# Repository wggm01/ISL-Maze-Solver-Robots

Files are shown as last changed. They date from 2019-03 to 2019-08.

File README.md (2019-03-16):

# Maze-Solver-Robots
We are working on a proposal to teach secondary teachers how to develop robots that are capable of solving a maze using open source platforms like Arduino and Raspberry.

Project Members:

Javier Romero.
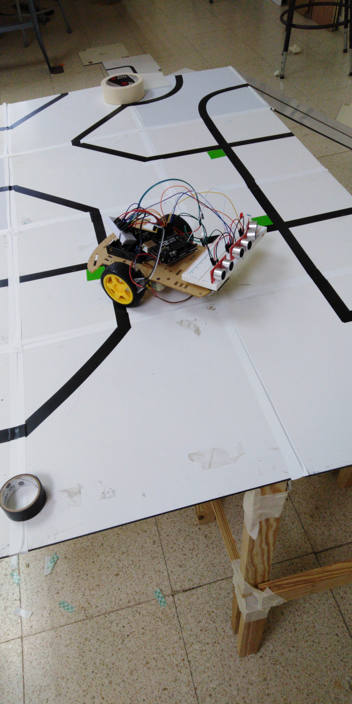
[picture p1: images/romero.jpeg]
Romero
> 

Fatima Batista.
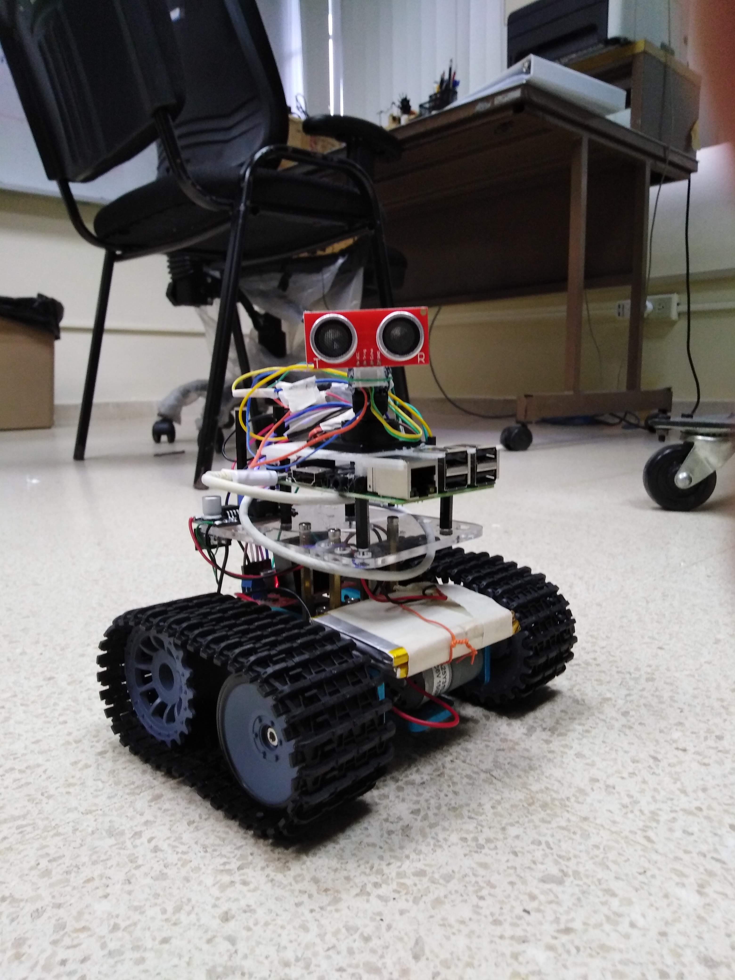
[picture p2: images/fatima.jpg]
Fatima
> 

Sobenis.
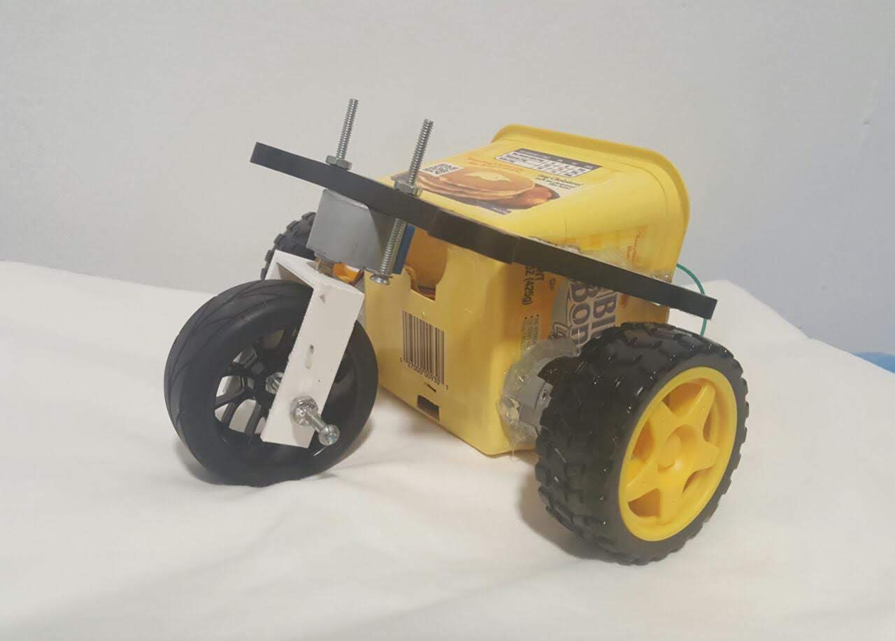
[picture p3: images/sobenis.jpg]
Sobenis
> 

Gabriel Marzullo.
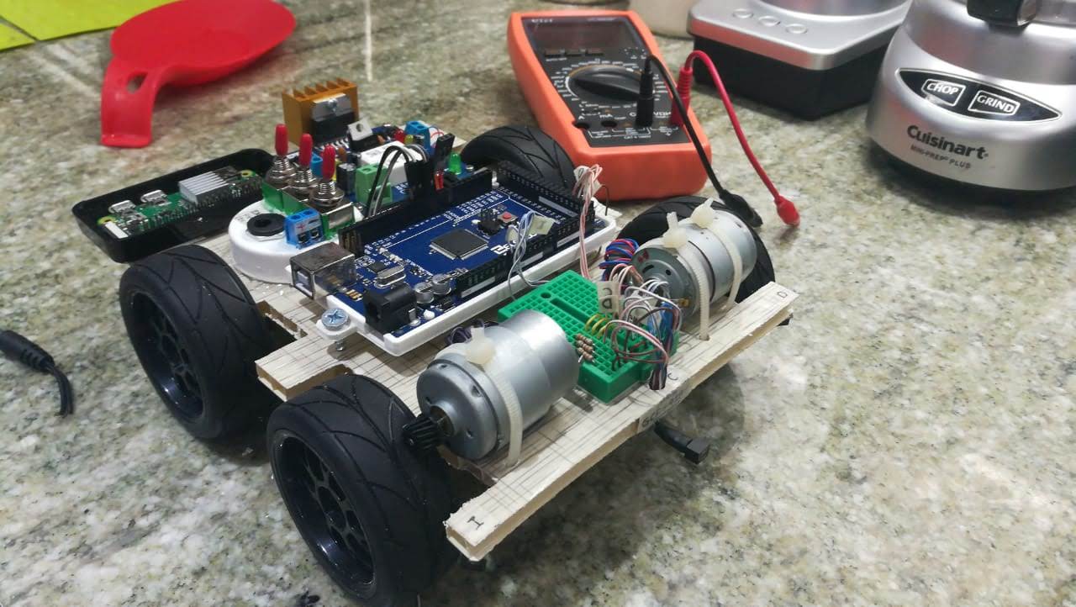
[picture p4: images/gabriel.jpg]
> 

Logistical info: 

Team Name: Intelligent-Systems-Laboratory

Organization: Technological University of Panama

Country: Panama 

Contact person: Danilo Caceres 

Email: danilo.caceres@utp.ac.pa

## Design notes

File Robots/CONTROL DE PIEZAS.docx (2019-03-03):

Articulo | Cantidad | Link | Imagen | Persona | Cantidad

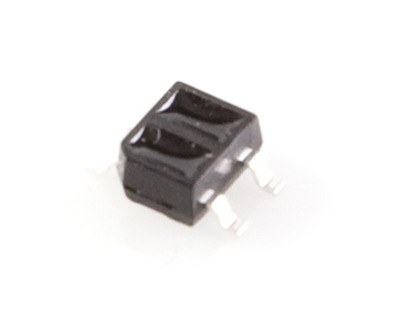
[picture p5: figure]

IR Reflectance Sensor - QRE1113 | 6 | https://www.sparkfun.com/products/9542 | | | 0[actualmente no se donde quedaron]
Optical Detector / Phototransistor - QRD1114 | 6 | https://www.sparkfun.com/products/246 | | Gabriel Marzullo | 3
Mini Photocell | 12 | https://www.sparkfun.com/products/9088 | | Gabriel Marzullo | 2

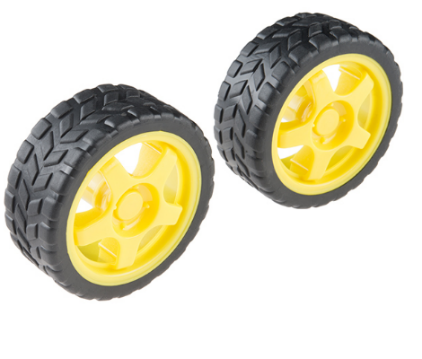
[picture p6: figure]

Wheel - 65mm (Rubber Tire, Pair) | 12 | https://www.sparkfun.com/products/13259 | | Sobenis Javier Romero | 0 2

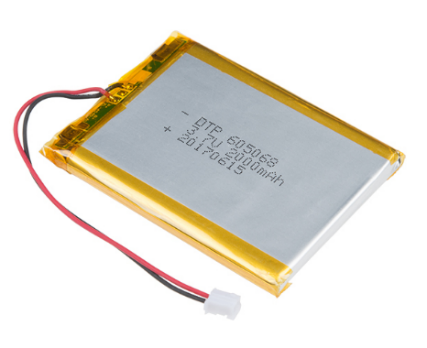
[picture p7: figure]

Baterias | 17 | https://www.sparkfun.com/products/13855 | | Gabriel Marzullo Sobenis Wvaldo Graell UDELAS | 3 0 3 3

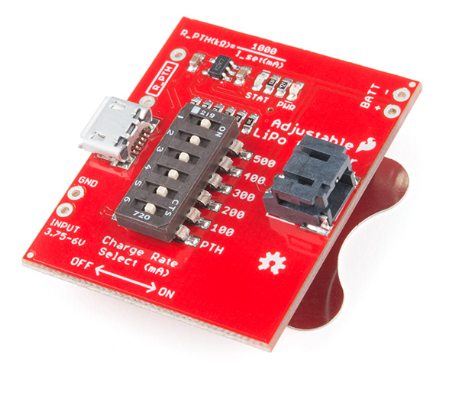
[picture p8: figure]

Cargadores | 6 | https://www.sparkfun.com/products/14380 | | Wvaldo Graell Sobenis Gabriel UDELAS | 1 0 1 1
Regulador de voltaje a 5v | 6 | https://www.sparkfun.com/products/107 | | Gabriel Marzullo | 1

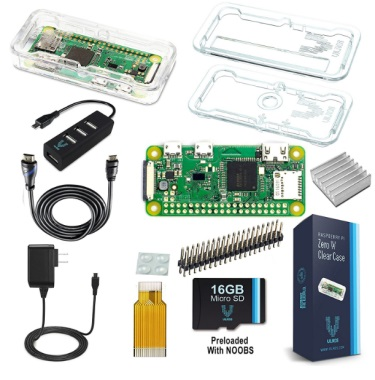
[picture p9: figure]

Raspberry pi Zero | 3 | https://www.amazon.com/gp/product/B0748M1Z1B/ref=ox_sc_sfl_title_1?ie=UTF8&psc=1&smid=AHALS71WJO58T | | Gabriel UDELAS Javier Romero | 1 1 1

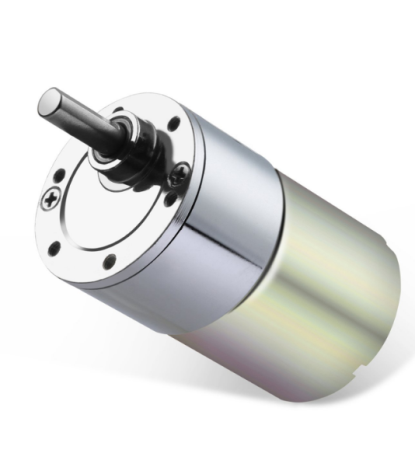
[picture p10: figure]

Motor Dc Con caja reductora | 12 | https://www.amazon.com/gp/product/B072N84V8S/ref=ox_sc_sfl_title_2?ie=UTF8&psc=1&smid=A18IHNL4DD28Y | | Billy Sobenis | 1 0

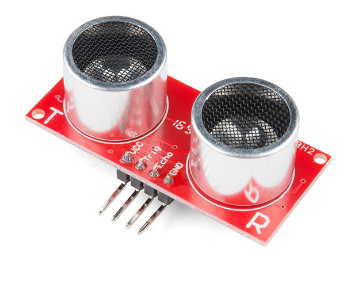
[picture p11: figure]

Sensor Ultrasonico SR-04 | 12 | https://www.sparkfun.com/products/13959 | | Sobenis Javier Romero Wvaldo UDELAS | 0 5 1 2

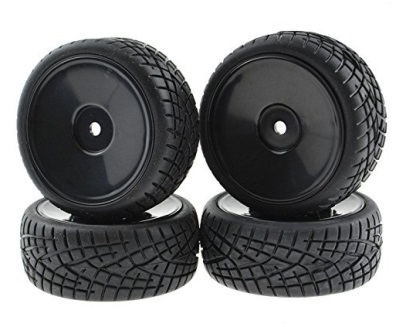
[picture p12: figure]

Llantas con rines | 12 | https://www.amazon.com/gp/product/B01HCVYJ5Q/ref=ox_sc_sfl_title_5?ie=UTF8&psc=1&smid=A9BS2LDT3QKQL | | Gabriel Sobenis Wvaldo | 4[set] 0 4[set]

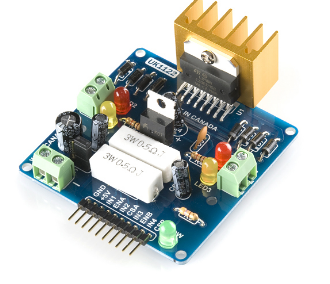
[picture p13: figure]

L298N | 12 | https://www.sparkfun.com/products/9670 | | Gabriel Sobenis Javier | 1 0 1

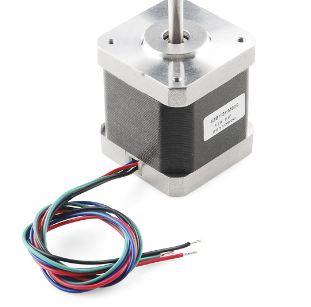
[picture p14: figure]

Stepper Motor - 68 oz.in (400 steps/rev) | 6 | https://www.sparkfun.com/products/10846 | | Wvaldo | 2

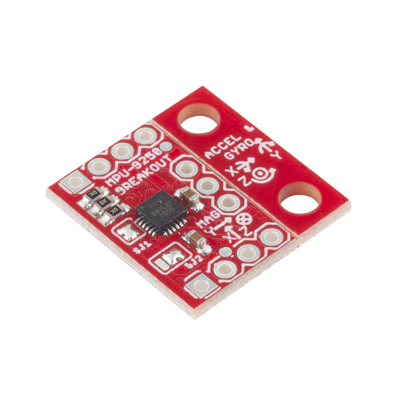
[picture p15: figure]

IMU-Gyroscope (no gimbals) MPU-9250 | 4 | https://www.sparkfun.com/products/13762 | | Gabriel Wvaldo UDELAS | 1 1 1

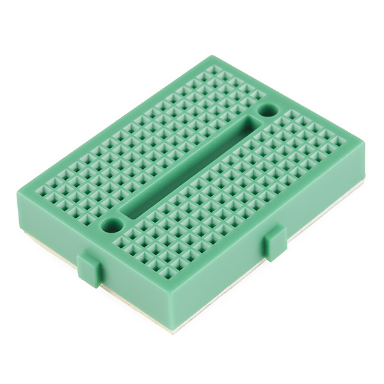
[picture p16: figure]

Mini protoboard modular | 5 | https://www.sparkfun.com/products/12046 | | Sobenis Gabriel Marzullo | 0 1

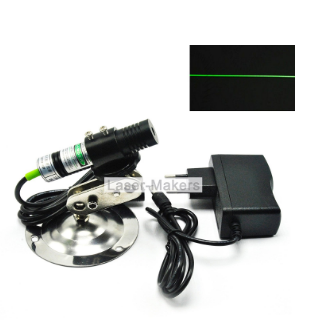
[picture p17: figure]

Laser line | 1 | https://www.amazon.com/gp/product/B00UCMXLXE/ref=ox_sc_sfl_title_8?ie=UTF8&psc=1&smid=A2W34SCE89LQ9K | | Gabriel | Llego 1 actualmente nadie lo usa[29-5-19]
Extensor para camara | 3 | https://www.amazon.com/gp/product/B0748DPHYQ/ref=ox_sc_sfl_title_9?ie=UTF8&psc=1&smid=A1N6DLY3NQK2VM

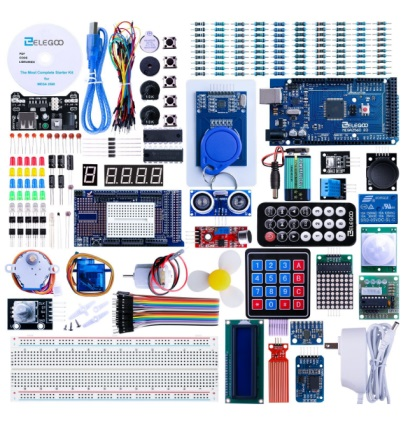
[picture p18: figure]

Arduino MEGA | 3 | https://www.amazon.com/gp/product/B01EWNUUUA/ref=ox_sc_sfl_title_10?ie=UTF8&psc=1&smid=A2WWHQ25ENKVJ1

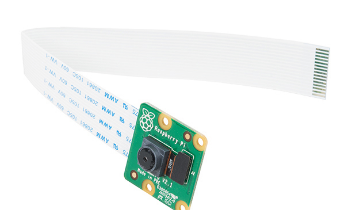
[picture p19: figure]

RPI CAMERA MODULO V2 | 3 | https://www.sparkfun.com/products/14028

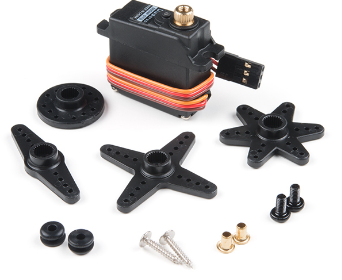
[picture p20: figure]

Servo - Generic Metal Gear (Micro Size) | 6 | https://www.sparkfun.com/products/14760 | | Gabriel Wvaldo Graell | 1 3

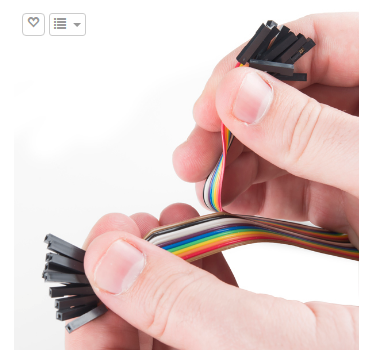
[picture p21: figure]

Jumpers hembra-hembra | 4 | https://www.sparkfun.com/products/12796

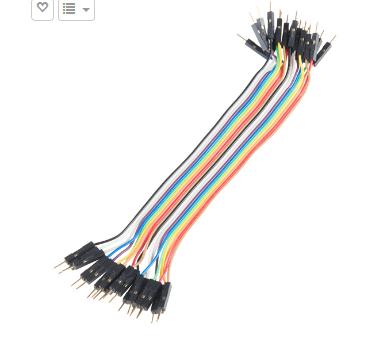
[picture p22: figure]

Jumpers macho-macho | 4 | https://www.sparkfun.com/products/12795

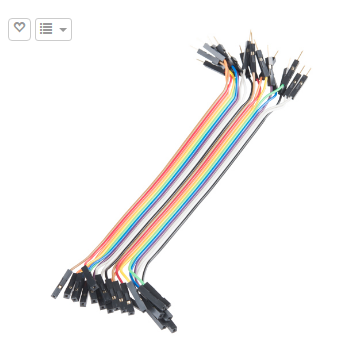
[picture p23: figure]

Jumpers macho-hembra | 4 | https://www.sparkfun.com/products/12794

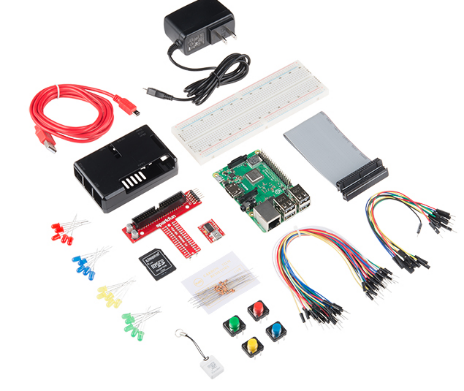
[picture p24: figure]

Raspberry pi 3 model b+ | 3 | https://www.sparkfun.com/products/14644 | | Wvaldo Kelvin | 1 1
Arduino Mega expansionshield | 3 | https://www.sparkfun.com/products/14753 | | Gabriel

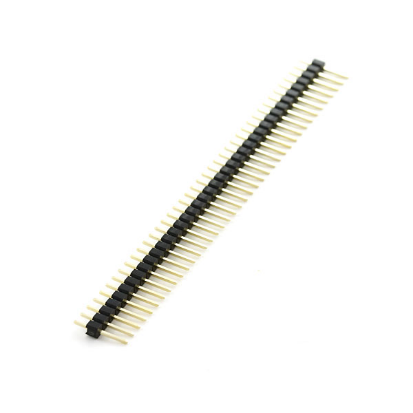
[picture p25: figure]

Header pins macho | 8 | https://www.sparkfun.com/products/116 | | Wvaldo | 1

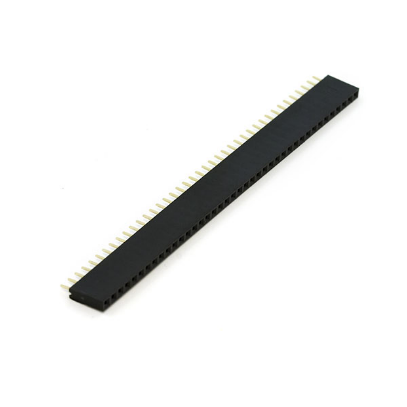
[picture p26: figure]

Header pins hembra | 20 | https://www.sparkfun.com/products/115

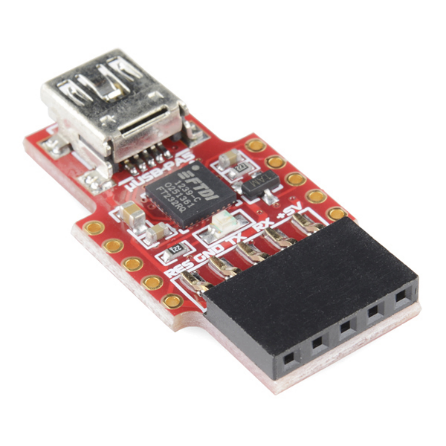
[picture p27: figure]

Puente USB a puerto SERIAL | 1 | https://www.sparkfun.com/products/11814

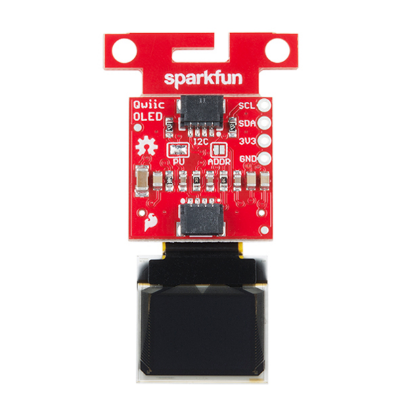
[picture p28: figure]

Pantalla micro OLED | 3 | https://www.sparkfun.com/products/14532 | | Gabriel Wvaldo | 1 1

*Los Artículos con enlaces en negrita no se consiguieron en sparkfun o no estaban disponibles en kits.

ROBOCUP JUNIOR 2018 RESCUE MAZE

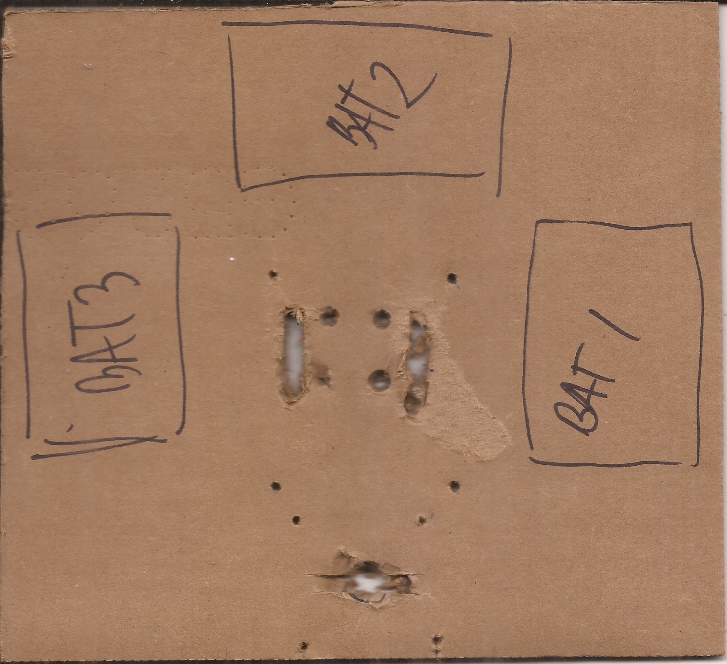
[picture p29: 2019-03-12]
Robots/Fatima/MEJORAS/Nivel2.jpg

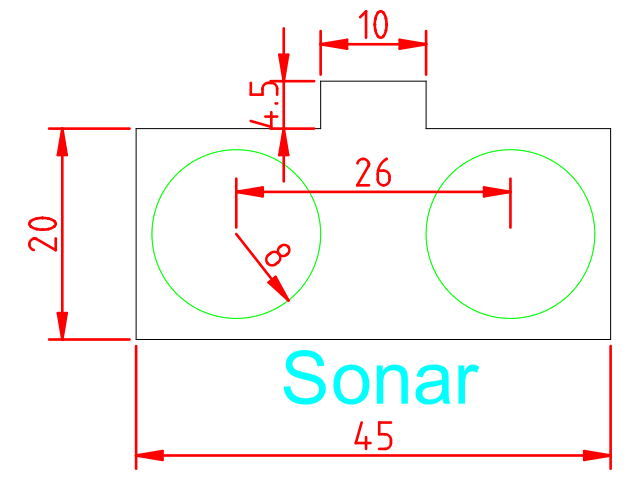
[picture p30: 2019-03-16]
Robots/Fatima/MEJORAS/sonar_anotaciones.png

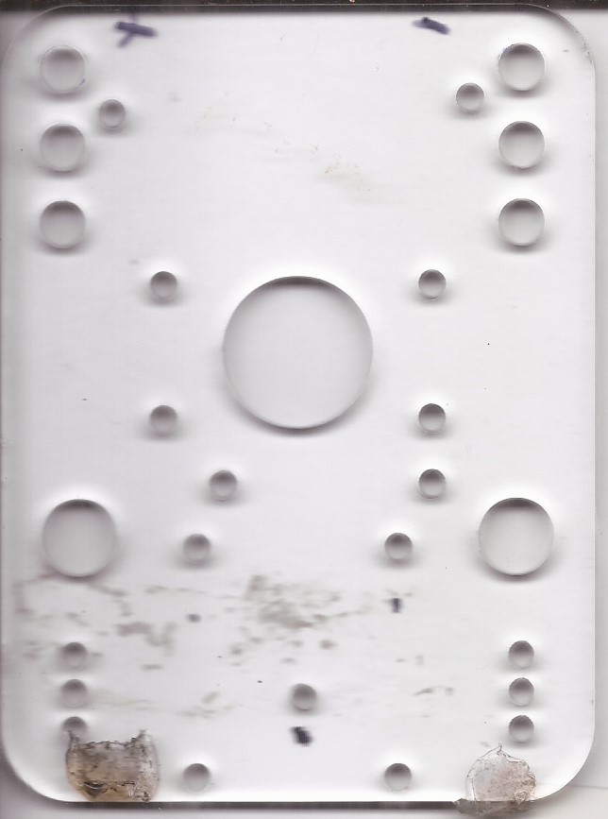
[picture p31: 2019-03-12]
Robots/Fatima/MEJORAS/base de arriba.jpg

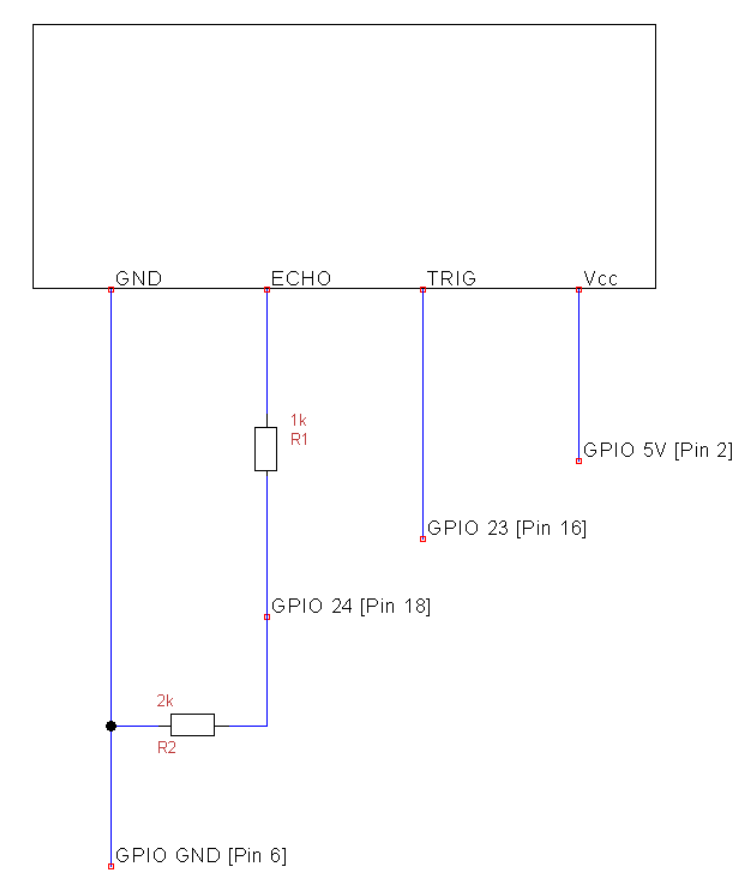
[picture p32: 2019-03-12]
Robots/Fatima/GRAFICOS/divisor.PNG

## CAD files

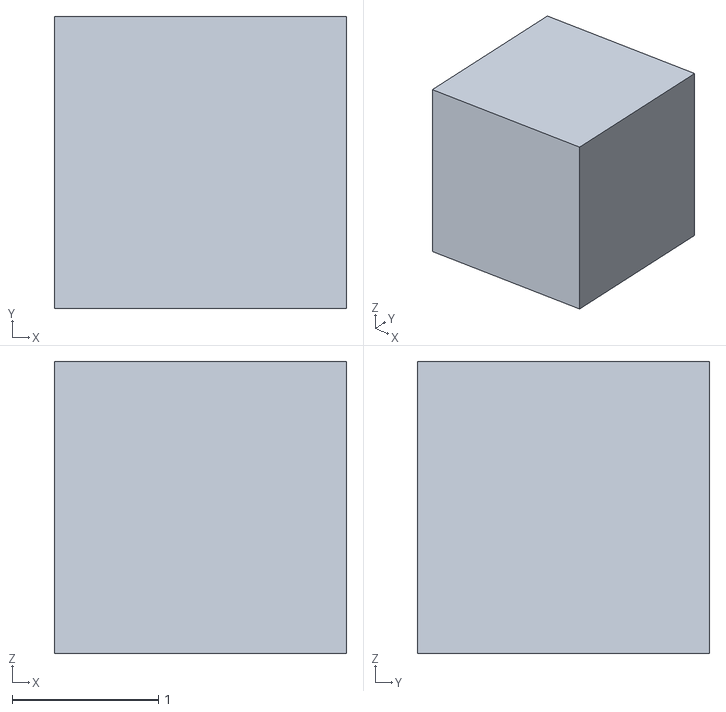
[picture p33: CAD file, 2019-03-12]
Robots/Fatima/IMUvi/data/box/box-C3F_V3F.obj
2.00 x 2.00 x 2.00

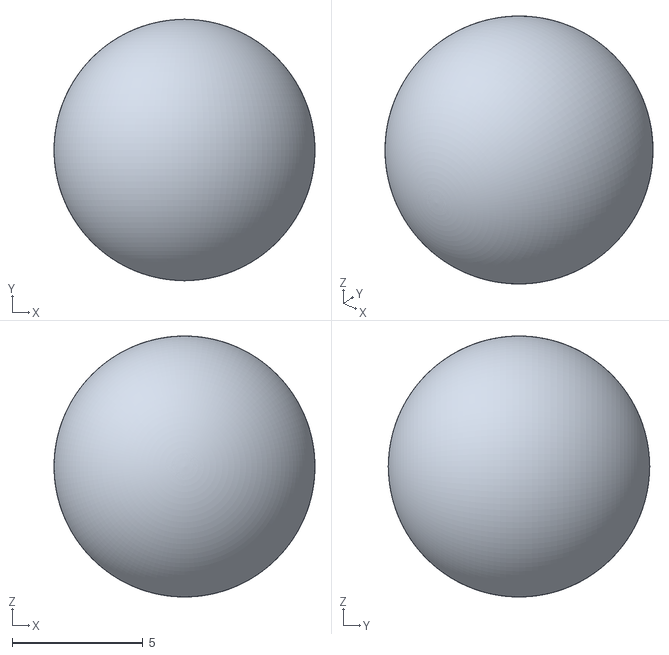
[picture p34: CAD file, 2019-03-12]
Robots/Fatima/IMUvi/data/usados/earth.obj
9.98 x 10.00 x 9.98

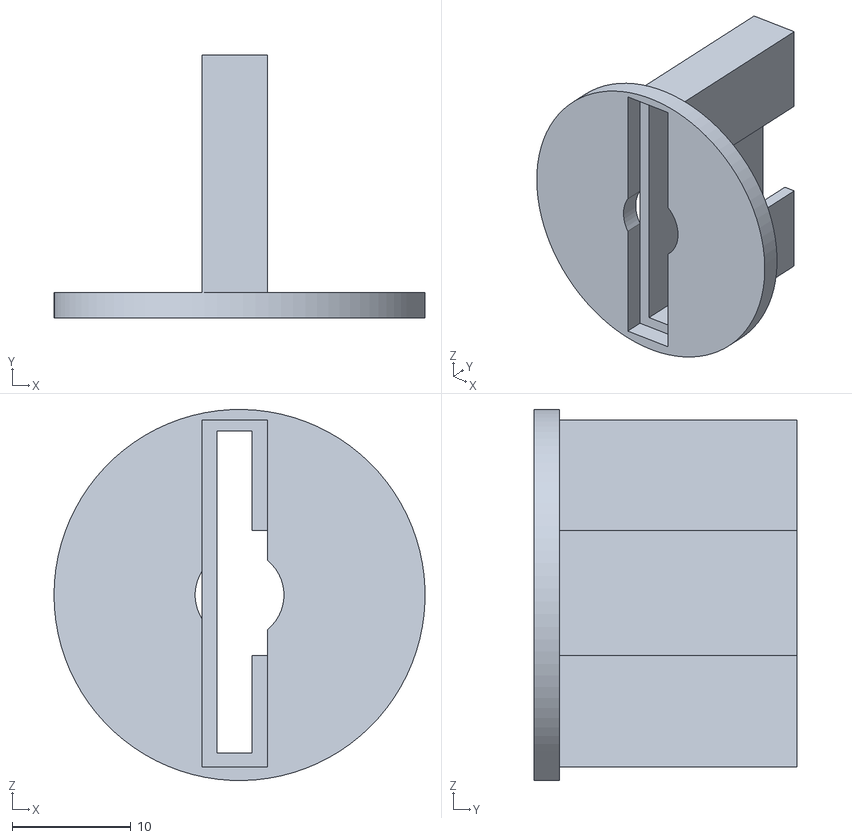
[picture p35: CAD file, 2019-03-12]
Robots/Fatima/IMUvi/Frpi.obj
31.2 x 22.1 x 31.2

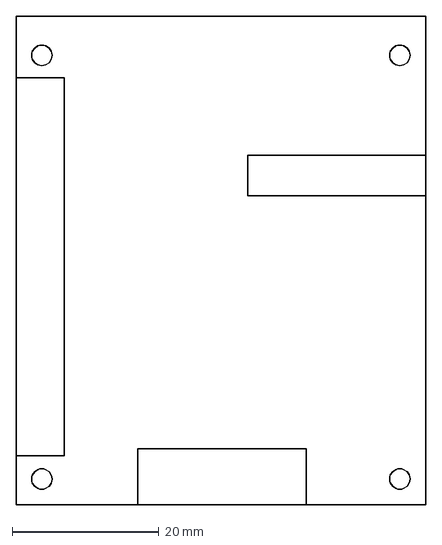
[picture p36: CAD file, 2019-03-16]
Robots/Fatima/MEJORAS/test ajuste rpi.dxf
55.8 x 66.6 mm

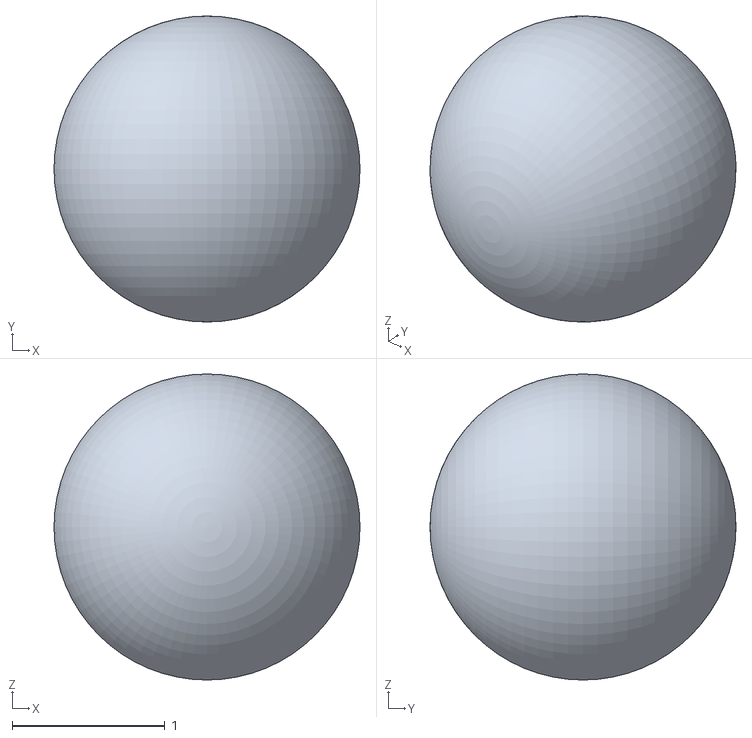
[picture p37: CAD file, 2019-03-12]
Robots/Fatima/not used/data/usados/uv_sphere.obj
2.00 x 2.00 x 2.00

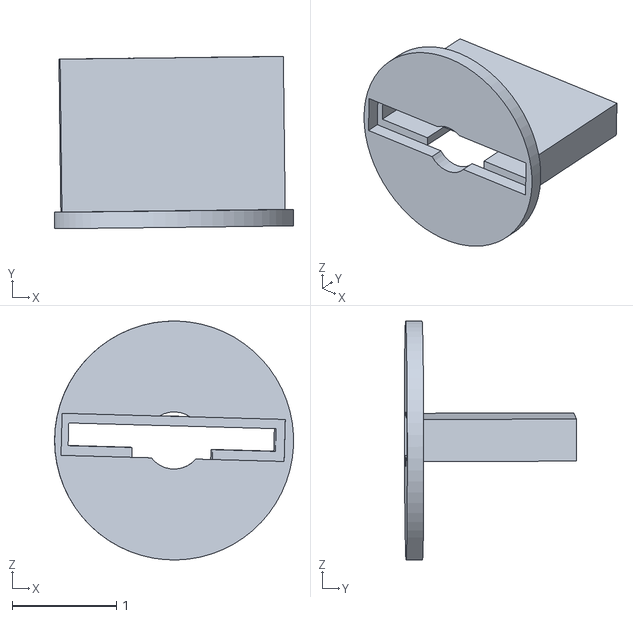
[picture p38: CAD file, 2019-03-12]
Robots/Fatima/IMUvi/data/usados/testobj.obj
2.29 x 1.65 x 2.29

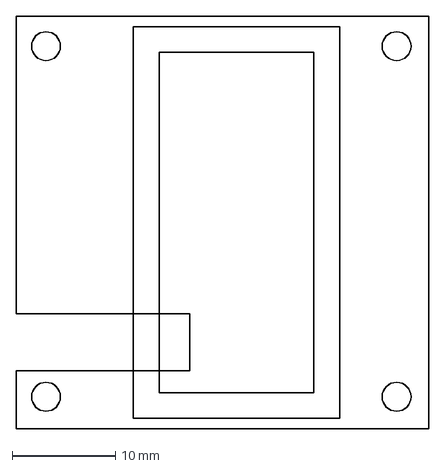
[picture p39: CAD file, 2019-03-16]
Robots/Fatima/MEJORAS/test ajuste servo.dxf
40.0 x 40.0 mm

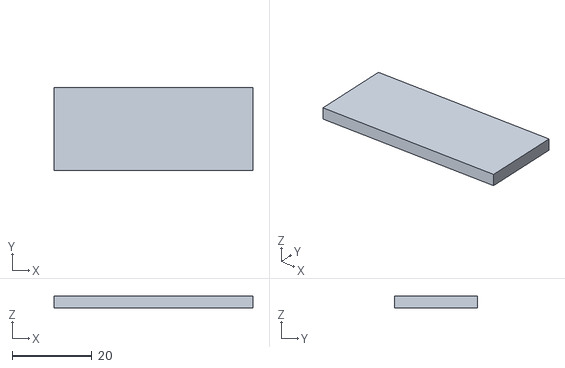
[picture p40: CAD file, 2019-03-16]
Robots/Fatima/MEJORAS/LockHCSR04.stl
50.0 x 20.8 x 3.00

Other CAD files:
Robots/Fatima/IMUvi/data/CUBE.obj
Robots/Fatima/not used/data/box/box-T2F_N3F_V3F.obj
Robots/Fatima/not used/data/CUBE.obj
Robots/Fatima/IMUvi/data/box/box-V3F.obj
Robots/Fatima/not used/data/box/box-T2F_V3F.obj
Robots/Fatima/IMUvi/data/box/box-T2F_N3F_V3F.obj
Robots/Fatima/not used/data/box/box-T2F_C3F_V3F.obj
Robots/Fatima/not used/data/usados/testobj2.obj
Robots/Fatima/IMUvi/data/box/box-N3F_V3F.obj
Robots/Fatima/IMUvi/data/box/box-T2F_C3F_V3F.obj
Robots/Fatima/IMUvi/data/box/box-T2F_V3F.obj
Robots/Fatima/IMUvi/data/usados/testobj2.obj
Robots/Fatima/MEJORAS/Base Radar.stl
Robots/Fatima/MEJORAS/Base para Servo.stl
Robots/Fatima/MEJORAS/CONTROL.dxf
Robots/Fatima/MEJORAS/CoverHCSR04.stl
Robots/Fatima/MEJORAS/SISTEMA DE BATERIAS.dxf
Robots/Fatima/MEJORAS/pcblocations.dxf
Robots/Fatima/MEJORAS/pn1.dxf
Robots/Fatima/MEJORAS/pn2.dxf
Robots/Fatima/MEJORAS/sonar_cotas.dxf
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

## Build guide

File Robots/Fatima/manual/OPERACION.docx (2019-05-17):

OPERACION | LED | MENSAJE EN OLED(I2C)
INICIO DE PROGRAMA | SE MANTIENE ENCENDIDO HASTA QUE EL ARDUINO SE INICIALIZE | INICIO DE PROGRAMA
ELECCION DE MODO | CONMUTA CADA 0.25S HASTA QUE SE ELIJA UN MODO, CUANDO SE ELIJE UN MODO DE SE APAGA | SELECCIONE MODO: B1 MAZE B2 MANUAL

MODO MAZE
ACTIVACION DEBUG | NO REALIZA NINGUNA OPERACION | B1 DEBUG B2 !DEBUG
MODO MAZE ACTIVO | LED PARPADEA CADA 1S TRES VECES | MODO MAZE ACTIVO: TIME: 00:00:00
REINICIO DE PROGRAMA(b1) MODO MAZE ACTIVO | NO HACE NADA | SEE YOU
CIERRE DE PROGRAMA(b2) MODO MAZE ACTIVO | NO HACE NADA | BYE BYE
MODO MANUAL ACTIVO | LED PARPADE 5 VECES CADA 0.5S | MODO MANUAL ACTIVO
BLE SERVER | NO HACE NADA | BLE WAITING
TCP SERVER | NO HACE NADA | TCP WAITING
REINICIO DE PROGRAMA(b1) MODO MANUAL ACTIVO | NO HACE NADA | SEE YOU
CIERRE DE PROGRAMA(b2) MODO MANUAL ACTIVO | NO HACE NADA | BYE BYE

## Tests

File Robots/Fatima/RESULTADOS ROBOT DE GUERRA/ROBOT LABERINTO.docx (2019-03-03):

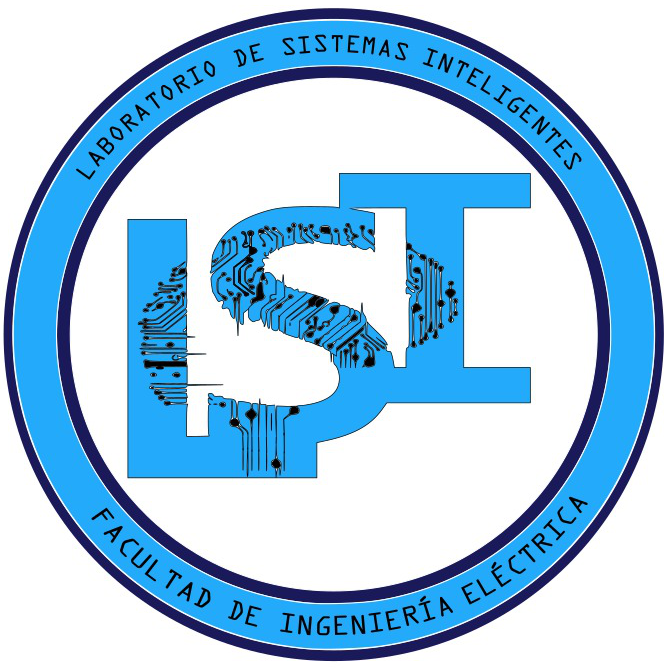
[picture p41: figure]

# ROBOT LABERINTO

UNIDAD AUTONOMA CON NAVEGACION MEDIANTE TECNICAS DE TRATAMIENTO DE SEÑALES DIGITALES

Wvaldo Graell | Josue Rodriguez

Asesores: Danilo Caceres | Fernando Merchan

Laboratorio de Sistemas Inteligentes

Datos Recolectados el 18 de mayo de 2019 hora: 9:30pm

[NOTA: EN TODOS LOS ESCENARIOS CERO GRADOS ESTA A LA DERECHA ]

[ESCENARIO SIN SALIDA]

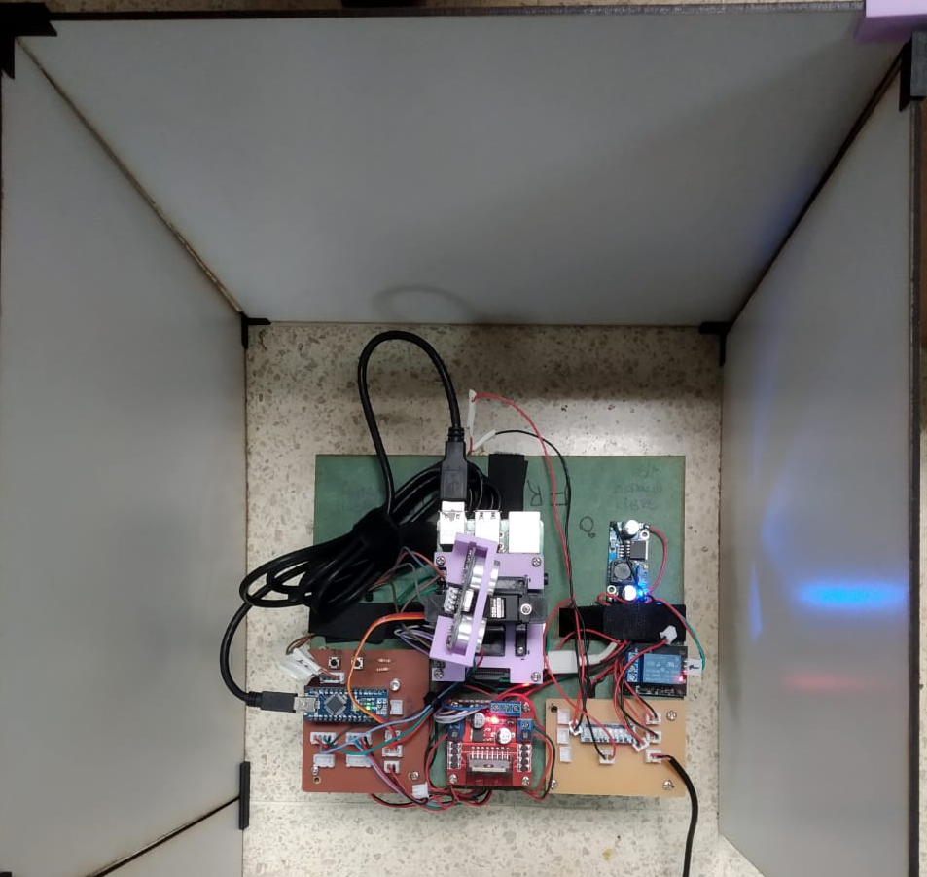
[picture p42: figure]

[GRAFICO EN COORDENADAS RECTANGULARES]

[GRAFICO DE GRADOS VS DISTANCIA]

[ESCENARIO GIRO A LA DERECHA]

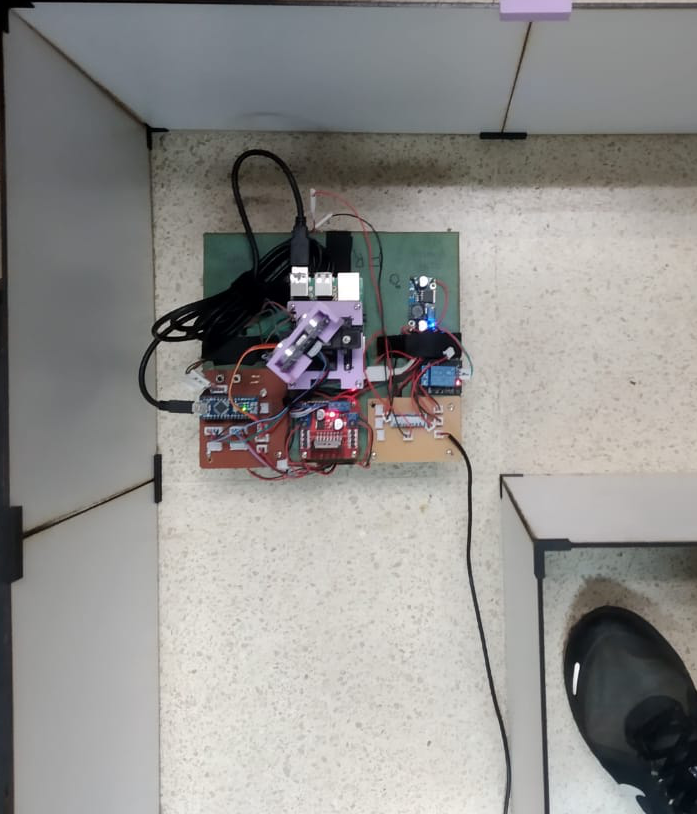
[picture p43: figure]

[GRAFICO EN COORDENADAS RECTANGULARES]

[GRAFICO DE GRADOS VS DISTANCIA]

[ESCENARIO SEGUIR DERECHO]

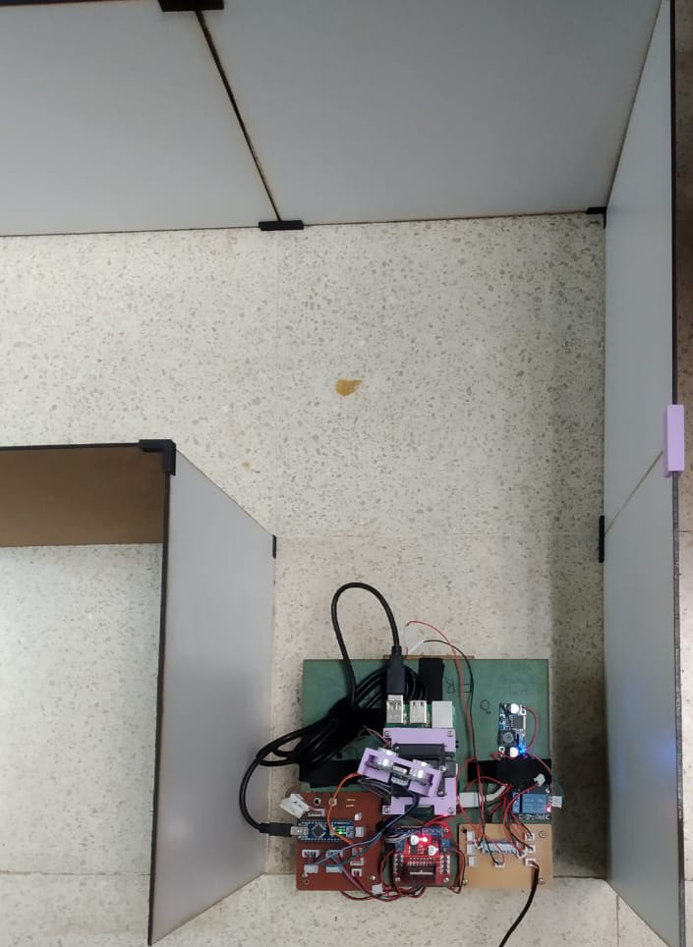
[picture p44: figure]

[GRAFICO EN COORDENADAS RECTANGULARES]

[GRAFICO DE GRADOS VS DISTANCIA]

[ESCENARIO GIRO A LA IZQUIERDA]

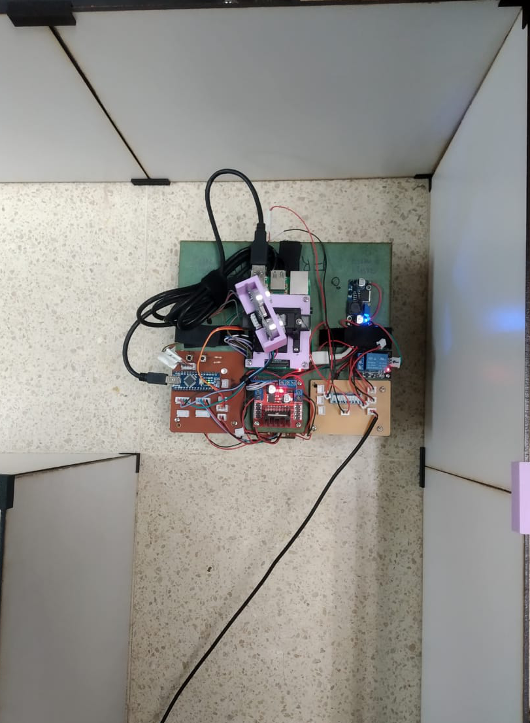
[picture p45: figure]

[GRAFICO EN COORDENADAS RECTANGULARES]

[GRAFICO DE GRADOS VS DISTANCIA]

[EL CODIGO QUE CONTROLA AL SERVO ESTA LIMITADO DE 5 A 170 GRADOS ESTO SE HIZO PORQUE EL REGULADOR DE 5V QUE ALIMENTA AL SERVO PRESENTABA BAJO VOLTAJE CUANDO EL SERVO LLEGABA A LOS EXTREMOS ]

[EL CODIGO QUE CONTROLA AL SENSOR DE DISTANCIA ESTA LIMITADO A 40 CM]

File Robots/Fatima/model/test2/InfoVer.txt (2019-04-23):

GravoStyle GS7 Build 3
7.0.0.0 build B003 at 29/11/2012

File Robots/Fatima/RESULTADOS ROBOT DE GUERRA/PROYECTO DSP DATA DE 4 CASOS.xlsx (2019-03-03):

Grados | Distancia | Radianes | RectX | RectY | GRAFICA EN RECTANGULAR |  |  |  |  |  |  | GRAFICA ANGULO EN GRADOS VS DISTANCIA |  | ESCENARIO
6 | 0 | 0.1047197551 | 0 | 0
7 | 13 | 0.1221730476 | 12.90309997 | 1.584301464
8 | 13 | 0.1396263402 | 12.87348489 | 1.809250312
9 | 13 | 0.1570796327 | 12.83994843 | 2.033648046
10 | 13 | 0.1745329252 | 12.80250079 | 2.25742631
11 | 15 | 0.1919862177 | 14.72440775 | 2.862134931
12 | 13 | 0.2094395102 | 12.71591881 | 2.702851981
13 | 13 | 0.2268928028 | 12.66681084 | 2.924363706
14 | 13 | 0.2443460953 | 12.61384444 | 3.144984643
15 | 14 | 0.2617993878 | 13.52296157 | 3.623466631
16 | 13 | 0.2792526803 | 12.49640205 | 3.583285626
17 | 13 | 0.2967059728 | 12.43196183 | 3.800832161
18 | 13 | 0.3141592654 | 12.36373471 | 4.017220927
19 | 13 | 0.3316125579 | 12.29174148 | 4.232386008
20 | 13 | 0.3490658504 | 12.21600407 | 4.446261863
21 | 13 | 0.3665191429 | 12.13654554 | 4.658783344 |  |  |  |  |  |  |  |  |  | SIN SALIDA
22 | 13 | 0.3839724354 | 12.05339011 | 4.869885714
23 | 13 | 0.401425728 | 11.96656309 | 5.07950467
24 | 13 | 0.4188790205 | 11.87609095 | 5.28757636
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

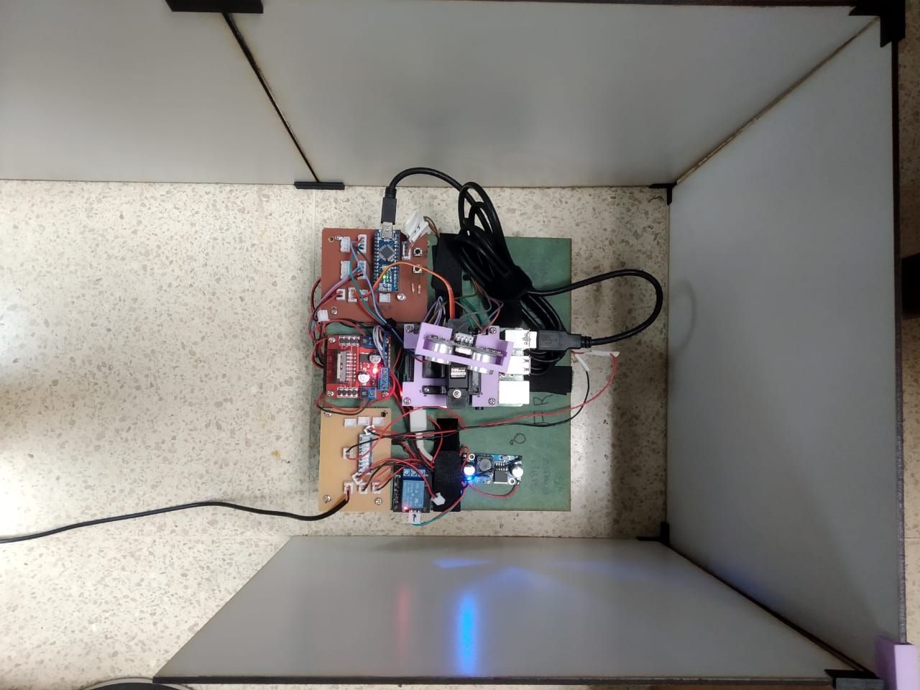
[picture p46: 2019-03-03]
Robots/Fatima/RESULTADOS ROBOT DE GUERRA/Encerrado.jpeg

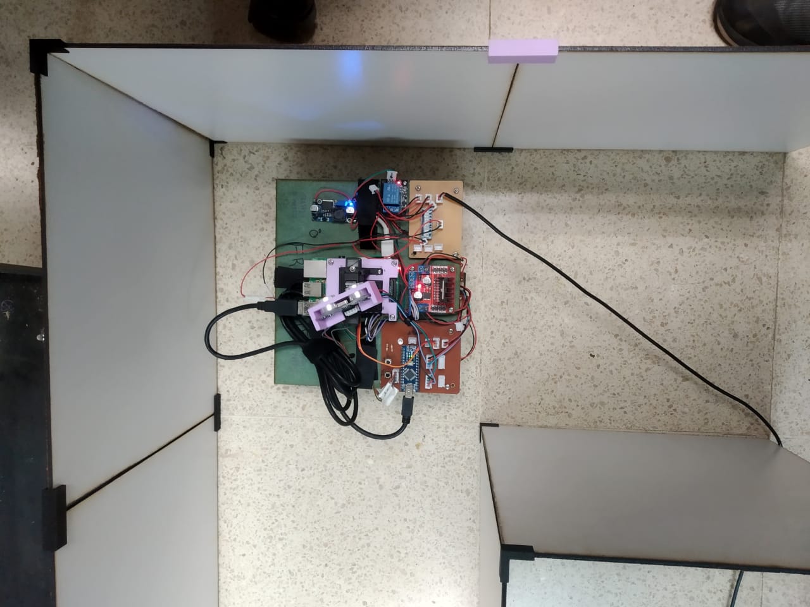
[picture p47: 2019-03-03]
Robots/Fatima/RESULTADOS ROBOT DE GUERRA/Giro a la izquierda.jpeg

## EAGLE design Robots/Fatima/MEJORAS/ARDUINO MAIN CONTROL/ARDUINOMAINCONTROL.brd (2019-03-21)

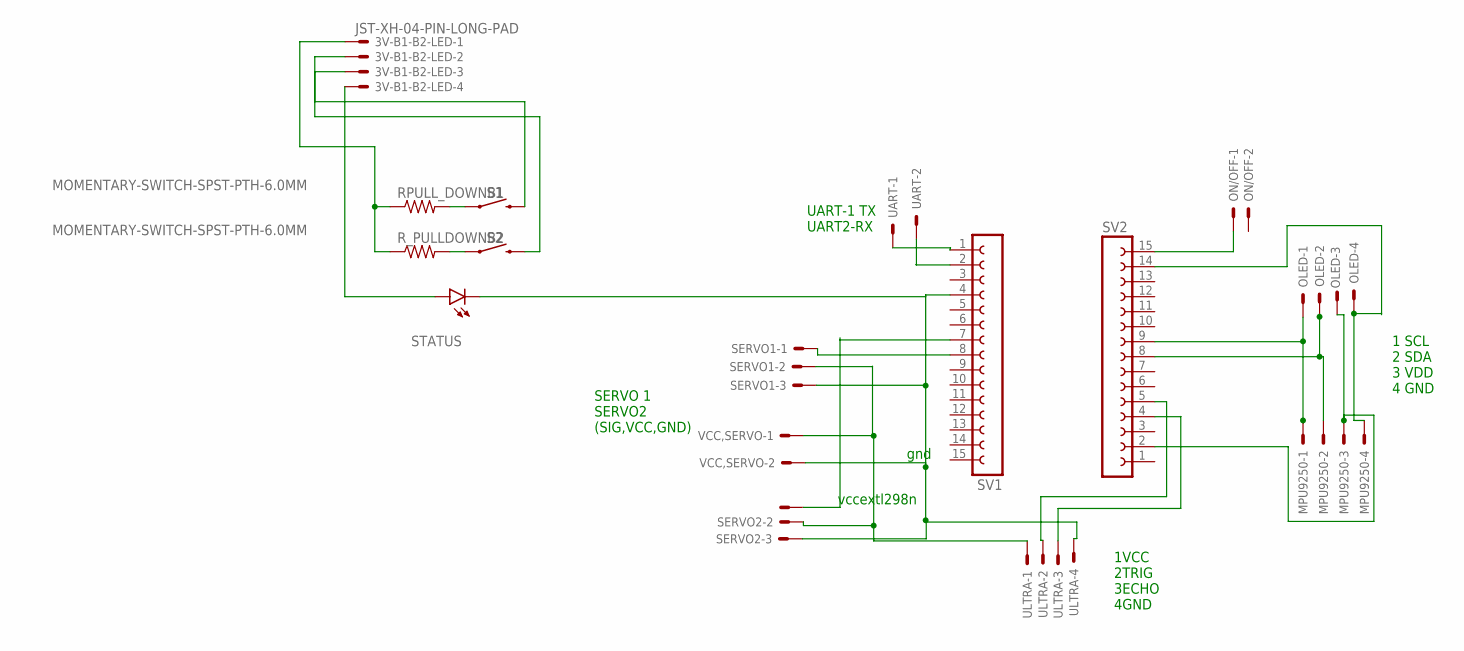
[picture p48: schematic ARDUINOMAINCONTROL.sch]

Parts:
3V-B1-B2-LED: JST-XH-04-PIN-LONG-PAD; JST-XH-04-PACKAGE-LONG-PAD
MPU9250: JST-XH-04-PIN-LONG-PAD; JST-XH-04-PACKAGE-LONG-PAD
OLED: JST-XH-04-PIN-LONG-PAD; JST-XH-04-PACKAGE-LONG-PAD
ON/OFF: JST-XH-02-PIN-LONG-PAD; JST-XH-02-PACKAGE-LONG-PAD
RPULL_DOWNB1: R-US_0207/10; 0207/10
R_PULLDOWNB2: R-US_0207/10; 0207/10
S1, S2: MOMENTARY-SWITCH-SPST-PTH-6.0MM; TACTILE_SWITCH_PTH_6.0MM
SERVO1, SERVO2: JST-XH-03-PIN-LONG-PAD; JST-XH-03-PACKAGE-LONG-PAD
STATUS: LED3MM
SV1, SV2: FE15-1; FE15
UART: JST-XH-02-PIN-LONG-PAD; JST-XH-02-PACKAGE-LONG-PAD
ULTRA: JST-XH-04-PIN-LONG-PAD; JST-XH-04-PACKAGE-LONG-PAD
VCC,SERVO: JST-XH-02-PIN-LONG-PAD; JST-XH-02-PACKAGE-LONG-PAD

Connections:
unnamed: MPU9250.1, OLED.1, SV2.9
unnamed: MPU9250.3, OLED.3, SV2.2
unnamed: MPU9250.4, OLED.4, SV2.14
unnamed: ON/OFF.1, SV2.15
unnamed: SV1.1, UART.1
unnamed: SV1.2, UART.2
unnamed: SERVO1.3, STATUS.K (C), SV1.4, ULTRA.4, VCC,SERVO.2
unnamed: SERVO1.2, ULTRA.1, VCC,SERVO.1
unnamed: SV2.4, ULTRA.3
unnamed: SV2.5, ULTRA.2
unnamed: RPULL_DOWNB1.2, S1.1
unnamed: R_PULLDOWNB2.2, S2.1
unnamed: SERVO1.1, SV1.8
unnamed: SERVO2.1, SV1.7
unnamed: 3V-B1-B2-LED.1, RPULL_DOWNB1.1, R_PULLDOWNB2.1
unnamed: 3V-B1-B2-LED.2, S1.3 (2)
unnamed: 3V-B1-B2-LED.3, S2.3 (2)
unnamed: 3V-B1-B2-LED.4, STATUS.A
unnamed: MPU9250.2, OLED.2, SV2.8

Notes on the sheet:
1 SCL 2 SDA 3 VDD 4 GND
UART-1 TX UART2-RX
SERVO 1 SERVO2 (SIG,VCC,GND)
1VCC 2TRIG 3ECHO 4GND
gnd
vccextl298n

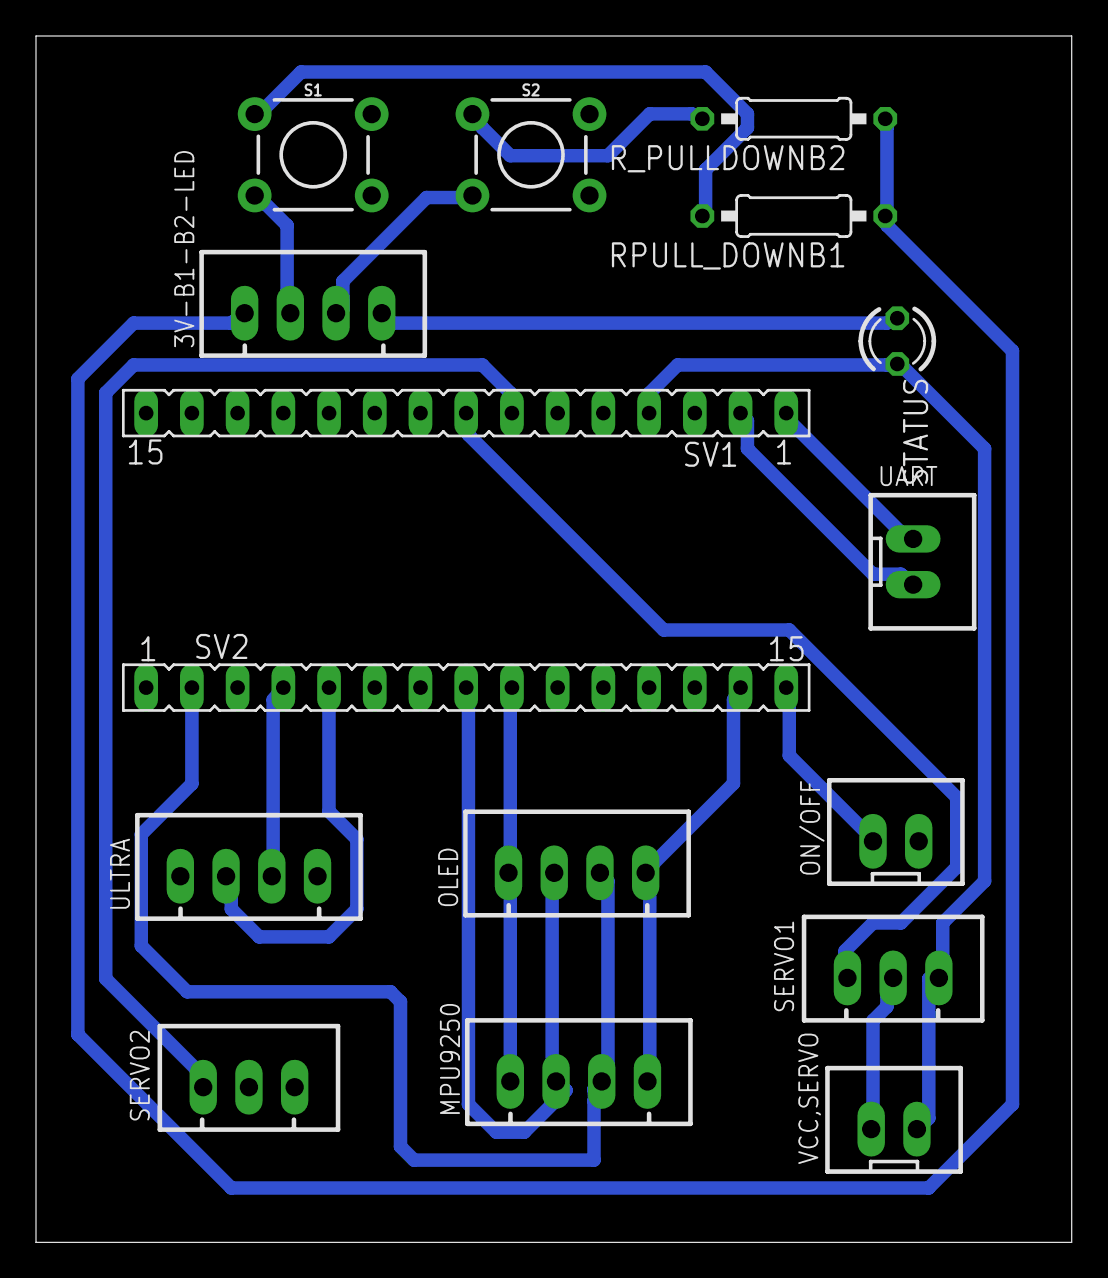
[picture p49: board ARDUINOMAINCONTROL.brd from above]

Board: 2 copper layers, 57.5 x 67.0 mm, 16 parts (0 on the bottom side), 19 nets.

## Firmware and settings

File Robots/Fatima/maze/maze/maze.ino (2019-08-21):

#include <Servo.h>
#include "MPU9250.h"
#include "math.h"
#define RAD_TO_DEG 57.295779513082320876798154814105
//MPU
MPU9250 IMU(Wire,0x68);
int status;
float gpitch,groll,gyaw;
float gyroRatex,gyroRatey,gyroRatez;
float accRatex,accRatey,accRatez;
float accpitch,accroll;
float pitch,roll,yaw;
//MPU
//Serial
char cmd[2];
int j=0;
boolean stringComplete = false;  // whether the string is complete
int flagSerial = 1; //control de envio de instrucciones
int flagIMU = 0;
int flagRadar = 0;
boolean send_Data=false;
//Serial
//Servos
Servo txServo;
int minPosX = 5; //Extremos que puede alcanzar el servo
int maxPosX = 170;
int lastPosX = 0; //Memoria de posicion anterior en x
int loopCount = 0; //Cuenta cuantos barridos se han hecho
int radius = 0; //guarda la distancia tomada en ese punto
int lastRadius = 0;//guarda la distancia pasada
boolean scanDirection = true; // Indica la direccion del servo
int scanIncrement = 1; //Suma un grado para el siguiente movimiento del servo
int posX = minPosX;//Posicion incial del servo
int servoattach=1;
//Servos
//HC-SR04
float distance; //crea la variable "distancia"
float tiempo; //crea la variable tiempo (como float)
#define TRIG_PIN A1
#define ECHO_PIN A0
//HC-SR04

//Control de Encoder
int encoCounter=0; //Contador de estados
int encoState=0; //Estado actual del encoder
int lastState=0; //Ultimo estado del encoder

//Control de Encoder

void setup() {
  //Encoder pines
  pinMode(2,INPUT);//D0 de encoder
  //Encoder pines
//   pinMode(LED_BUILTIN, OUTPUT); //Indicador de proceso de calibracion
  // initialize serial:
  Serial.begin(115200);
  //Servos
  txServo.attach(5);
  txServo.write(5);
  delay(500);
  txServo.detach();
  //Servos
  //HC-SR04
  pinMode(TRIG_PIN, OUTPUT);
  pinMode(ECHO_PIN, INPUT);
  //HC-SR04
  //MPU
 while(!Serial) {Serial.println("Problemas con IMU");}

  // start communication with IMU
  status = IMU.begin();
   if (status < 0) {
    Serial.println("IMU initialization unsuccessful");
    Serial.println("Check IMU wiring or try cycling power");
    Serial.print("Status: ");
    Serial.println(status);
    while(1) {}
  }
  // setting the accelerometer full scale range to +/-8G
  IMU.setAccelRange(MPU9250::ACCEL_RANGE_2G);
  // setting the gyroscope full scale range to +/-500 deg/s
  IMU.setGyroRange(MPU9250::GYRO_RANGE_250DPS);
  // setting DLPF bandwidth to 20 Hz
  IMU.setDlpfBandwidth(MPU9250::DLPF_BANDWIDTH_20HZ);
  // setting SRD to 19 for a 50 Hz update rate (cada 20 ms)
  IMU.setSrd(19);//frecuencia de actualizacion de datos del imu (magnetometroData Output Rate = 8Hz)

  //Calibracion de Gyro
  int gC = IMU.calibrateGyro();
  if (gC>0){
    Serial.println("Gyro calibrado");
//   for(int i=0; i<2; i++ ){
//    digitalWrite(LED_BUILTIN, HIGH);
//    delay(500);
//    digitalWrite(LED_BUILTIN, LOW);
//    } 
  }else{Serial.println("Error Gyro");}

 //Calibracion de Acce
 int aC =IMU.calibrateAccel();
  if (aC>0){
    Serial.println("Acce calibrado");
//   for(int i=0; i<3; i++ ){
//    digitalWrite(LED_BUILTIN, HIGH);
//    delay(500);
//    digitalWrite(LED_BUILTIN, LOW);
//    }
    }else{Serial.println("Error Gyro");}
  Serial.println("Mueva ligeramente el dispositivo");
//Calibracion magnetometro
 int mC =IMU.calibrateAccel();
 if (mC>0){
    Serial.println("Mag calibrado");
//   for(int i=0; i<4; i++ ){
//    digitalWrite(LED_BUILTIN, HIGH);
//    delay(500);
//    digitalWrite(LED_BUILTIN, LOW);
//    }
    }else{Serial.println("Error Gyro");}
  //MPU
  //Confirmacion de comunicacion
   for(int i=0; i<4; i++ ){
     Serial.println('1');
     delay(200);
    }
  //Confirmacion de comunicacion
}

//--------Funciones--------------//
bool moveServos(){
  bool moved = false;
  static int lastPosX;
  int delta = 0;
  if (posX != lastPosX) {
    txServo.write(posX);
    lastPosX = posX;
    moved = true;}
  delay(15);
  return moved;
}

int calculateDistance(){
  digitalWrite(TRIG_PIN,LOW);
  delayMicroseconds(5);
  digitalWrite(TRIG_PIN, HIGH);
  delayMicroseconds(10);
  tiempo = pulseIn(ECHO_PIN, HIGH,2915);
  int distancep = 0.01715*tiempo;
  if (distancep < 1){distancep=0;}
  return distancep;}

    void data_IMU(){
  IMU.readSensor();
  // display the data
  gyroRatex=IMU.getGyroX_rads();
  gyroRatey=IMU.getGyroY_rads();
  gyroRatez=IMU.getGyroZ_rads();
  gpitch +=(gyroRatex/50)*RAD_TO_DEG;
  groll +=(gyroRatey/50)*RAD_TO_DEG;
  gyaw +=(gyroRatez/50)*RAD_TO_DEG;
  accRatex=IMU.getAccelX_mss();
  accRatey=IMU.getAccelY_mss();
  accRatez=IMU.getAccelZ_mss();
  accRatex=accRatex*0.10197162129779;
  accRatey=accRatey*0.10197162129779;
  accRatez=accRatez*0.10197162129779;
  accpitch= atan(accRatex/sqrt(pow(accRatey,2) + pow(accRatez,2)))*(RAD_TO_DEG);
  accroll= atan(accRatey/sqrt(pow(accRatex,2) + pow(accRatez,2)))*(RAD_TO_DEG);
  //Filtro complementario:
  pitch = 0.97402*gpitch + accpitch*0.02598;
  roll = 0.97402*groll + accroll*0.02598;
  yaw= gyaw;
  Serial.print("I");
  Serial.print(",");
  Serial.print(pitch);
  Serial.print(",");
  Serial.print(roll);
  Serial.print(",");
  Serial.println(yaw);
}

void radar(){
  //for(int i=5;i<=180;i++){
  if (scanDirection) {
    posX += scanIncrement;} //ccw
  else {
    posX -= scanIncrement;}//cw
  if (posX > maxPosX || posX < minPosX) {
  	  // Cuando llega a uno de los dos limites cambia la direccion
      scanDirection = !scanDirection;}
  	posX = min(max(posX, minPosX), maxPosX);//Evita falla en la eleccion de grado
  	bool moved = moveServos();
    if (moved) {
    //Mandar distancia por UART cada vez que se mueve el servo
    distance = calculateDistance();
    //float rectx,recty;
    //rectx = distance*cos(posX);
    //recty = distance*sin(posX);
    if (scanDirection) {
      Serial.print("R");
      Serial.print(",");
      Serial.print("CCW");
      Serial.print(",");
      Serial.print(posX);
      Serial.print(",");
      Serial.println(distance);
      data_IMU();}
    }}
//--------Funciones--------------//

void loop() {
//PROCESO DE INICIALIZACION

if(servoattach==1){txServo.detach();}
if (flagSerial == 0){  //Controlo que este bloque se ejecute con la bandera.
  if (stringComplete) {
       char cmd1 = cmd[0];
      if (cmd1== '1'){ //el numero 1 se utiliza como indicador de estado
       for(int i=0 ; i<4 ; i++){
      Serial.println(cmd1);}}//Mensaje de retorno
      else{
        if (cmd1== 'R'){
            flagRadar = 1;
            servoattach=0;
            txServo.attach(5);}
            //Serial.println(cmd1);}//Activa la transmision de data de radar
        else if(cmd1== 'E'){
            flagRadar = 0;
            servoattach=1;
            posX=0;
            flagSerial=0;}
            //Serial.println(cmd1);}
            }
      // clear the string:
      cmd[0]='0'; cmd[1]='0';j=0;flagSerial = 0;
      stringComplete = false;}}

//CONTROL DE RADAR
if(flagRadar == 1){
radar();
  }

//Control de Encoder
char ena = cmd[0];
if(ena=='x'){ //Enviar x para inicar conteo y enviar s para detener
  encoState=digitalRead(2); //Estado actual del D0 del sensor
  if(encoState != lastState){
    if(encoState==HIGH){
      //OFF TO ON
      encoCounter++;
      if(encoCounter>11){encoCounter=0;cmd[0]='0';Serial.println('F');}}
    }lastState=encoState;
}
    
  } //END LOOP

void serialEvent() {
  while (Serial.available()) {
    char inChar = (char)Serial.read();
    //ACTIVA EL CODIGO EN EL LOOP
    flagSerial=0;
    // do something about it:
    cmd[j]=inChar;
    j = j+1;
    if (inChar == 's') {
      stringComplete = true;}}}

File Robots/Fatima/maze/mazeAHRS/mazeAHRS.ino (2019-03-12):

#include <hcsr04.h>
#include <Servo.h>
#include "quaternionFilters.h"
#include "MPU9250.h"

//MPU
#define AHRS true         
#define SerialDebug true
#define I2Cclock 400000
#define I2Cport Wire
#define MPU9250_ADDRESS MPU9250_ADDRESS_AD0
int status;
MPU9250 myIMU(MPU9250_ADDRESS, I2Cport, I2Cclock);
//MPU

//Serial
char cmd[2];
int j=0;
boolean stringComplete = false;  // whether the string is complete
int flagSerial = 1; //control de envio de instrucciones
int flagIMU = 0;
int flagRadar = 0;
//Serial
//Servos
Servo txServo;
//Servos
//HC-SR04
float distance;
#define TRIG_PIN A1
#define ECHO_PIN A0
HCSR04 rad(TRIG_PIN, ECHO_PIN, 20, 400);

//HC-SR04

void setup() {
  // initialize serial:
  Serial.begin(115200);
  //MPU
  Wire.begin();
  while(!Serial){}; //Evita que el programa incie sin el puerto serial
  byte c = myIMU.readByte(MPU9250_ADDRESS, WHO_AM_I_MPU9250);
  Serial.print(F("MPU9250 I AM 0x"));
  Serial.print(c, HEX);
  Serial.print(F(" I should be 0x"));
  Serial.println(0x71, HEX);
  if (c == 0x71) // WHO_AM_I should always be 0x68
  {
    // Start by performing self test and reporting values
   myIMU.MPU9250SelfTest(myIMU.selfTest);
    // Calibrate gyro and accelerometers, load biases in bias registers
   myIMU.calibrateMPU9250(myIMU.gyroBias, myIMU.accelBias);
   
    // Initialize device for active mode read of magnetometer
	myIMU.initMPU9250();
	Serial.println("MPU9250 initialized for active data mode....");
	byte d = myIMU.readByte(AK8963_ADDRESS, WHO_AM_I_AK8963);
    Serial.print("AK8963 ");
    Serial.print("I AM 0x");
    Serial.print(d, HEX);
    Serial.print(" I should be 0x");
    Serial.println(0x48, HEX);
	if (d != 0x48)
    {
      // Communication failed, stop here
      Serial.println(F("Communication failed, abort!"));
      Serial.flush();
      abort();
    }
	// Get magnetometer calibration from AK8963 ROM
    myIMU.initAK8963(myIMU.factoryMagCalibration);
    // Initialize device for active mode read of magnetometer
    Serial.println("AK8963 initialized for active data mode....");
	  myIMU.getAres();
    myIMU.getGres();
    myIMU.getMres();
  } // if (c == 0x71)
  else
  {
    Serial.print("Could not connect to MPU9250: 0x");
    Serial.println(c, HEX);
	// Communication failed, stop here
    Serial.println(F("Communication failed, abort!"));
    Serial.flush();
    abort();
  }
  //MPU

  //Servos
  txServo.attach(5);
  txServo.write(5);
  //Servos
}

//--------Funciones--------------//
void radar(){
  for(int i=5;i<=181;i++){  
  txServo.write(i);
  //delay(5);
  distance = calculateDistance();
  Serial.print("R");
  Serial.print(",");
  Serial.print("CCW"); 
  Serial.print(",");
  Serial.print(i);
  Serial.print(","); 
  Serial.print(distance); 
  //Serial.print(".");
  Serial.println("\n");
  //CONTROL DE IMU
if (flagIMU==1){
data_IMU();}
//CONTROL DE IMU 
  }
 
  for(int i=181;i>5;i--){  
  txServo.write(i);
  //delay(5);
  distance = calculateDistance();
  Serial.print("R");
  Serial.print(",");
  Serial.print("CW"); 
  Serial.print(","); 
  Serial.print(i);
  Serial.print(",");
  Serial.print(distance);
  //Serial.print(".");
  Serial.print("\n");
  //CONTROL DE IMU
if (flagIMU==1){
data_IMU();}
//CONTROL DE IMU 
  }}
int calculateDistance(){ 
   float distancemm=rad.distanceInMillimeters();
  float distancep= distancemm*0.1; //cm
  
  return distancep;}

  void data_IMU(){
	  myIMU.readAccelData(myIMU.accelCount);  // Read the x/y/z adc values

    
    // Now we'll calculate the accleration value into actual g's
    // This depends on scale being set
    myIMU.ax = (float)myIMU.accelCount[0]*myIMU.aRes; // - accelBias[0];
    myIMU.ay = (float)myIMU.accelCount[1]*myIMU.aRes; // - accelBias[1];
    myIMU.az = (float)myIMU.accelCount[2]*myIMU.aRes; // - accelBias[2];

    myIMU.readGyroData(myIMU.gyroCount);  // Read the x/y/z adc values
    
    
    // Calculate the gyro value into actual degrees per second
    // This depends on scale being set
    myIMU.gx = (float)myIMU.gyroCount[0]*myIMU.gRes;
    myIMU.gy = (float)myIMU.gyroCount[1]*myIMU.gRes;
    myIMU.gz = (float)myIMU.gyroCount[2]*myIMU.gRes;

    myIMU.readMagData(myIMU.magCount);  // Read the x/y/z adc values
    

	  myIMU.mx = (float)myIMU.magCount[0] * myIMU.mRes
               * myIMU.factoryMagCalibration[0] - myIMU.magBias[0];
    myIMU.my = (float)myIMU.magCount[1] * myIMU.mRes
               * myIMU.factoryMagCalibration[1] - myIMU.magBias[1];
    myIMU.mz = (float)myIMU.magCount[2] * myIMU.mRes
               * myIMU.factoryMagCalibration[2] - myIMU.magBias[2];
    


  // Must be called before updating quaternions!
  myIMU.updateTime();

  MahonyQuaternionUpdate(myIMU.ax, myIMU.ay, myIMU.az, myIMU.gx*DEG_TO_RAD,
                         myIMU.gy*DEG_TO_RAD, myIMU.gz*DEG_TO_RAD, myIMU.my,
                         myIMU.mx, myIMU.mz, myIMU.deltat);

  if (!AHRS)
  {
    myIMU.delt_t = millis() - myIMU.count;
    if (myIMU.delt_t > 3)
    {
      if(SerialDebug)
      {
		   int i =1; //Bypass
       /* // IMPRESION DE VALORES SIN USAR AHRS
        Serial.print("X-acceleration: "); Serial.print(1000*myIMU.ax);
        Serial.print(" mg ");
        Serial.print("Y-acceleration: "); Serial.print(1000*myIMU.ay);
        Serial.print(" mg ");
        Serial.print("Z-acceleration: "); Serial.print(1000*myIMU.az);
        Serial.println(" mg ");

        // Print gyro values in degree/sec
        Serial.print("X-gyro rate: "); Serial.print(myIMU.gx, 3);
        Serial.print(" degrees/sec ");
        Serial.print("Y-gyro rate: "); Serial.print(myIMU.gy, 3);
        Serial.print(" degrees/sec ");
        Serial.print("Z-gyro rate: "); Serial.print(myIMU.gz, 3);
        Serial.println(" degrees/sec");

        // Print mag values in degree/sec
        Serial.print("X-mag field: "); Serial.print(myIMU.mx);
        Serial.print(" mG ");
        Serial.print("Y-mag field: "); Serial.print(myIMU.my);
        Serial.print(" mG ");
        Serial.print("Z-mag field: "); Serial.print(myIMU.mz);
        Serial.println(" mG");

        myIMU.tempCount = myIMU.readTempData();  // Read the adc values
        // Temperature in degrees Centigrade
        myIMU.temperature = ((float) myIMU.tempCount) / 333.87 + 21.0;
        // Print temperature in degrees Centigrade
        Serial.print("Temperature is ");  Serial.print(myIMU.temperature, 1);
        Serial.println(" degrees C");*/
      }
      myIMU.count = millis();
    } // if (myIMU.delt_t > 500)
  } // if (!AHRS)
  else
  {
    // Serial print at 0.5 s rate independent of data rates
    myIMU.delt_t = millis() - myIMU.count;

    if (myIMU.delt_t > 3)
    {
      if(SerialDebug)
      {
		    int i =1; //Bypass
       /* Serial.print("ax = "); Serial.print((int)1000*myIMU.ax);
        Serial.print(" ay = "); Serial.print((int)1000*myIMU.ay);
        Serial.print(" az = "); Serial.print((int)1000*myIMU.az);
        Serial.println(" mg");
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

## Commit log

2019-03-03 Elminando vieja toma de datos
    [reg0-180.csv]
2019-03-13 Prueba sin Analizar data de mpu9250
2019-03-14 Solo falta data imu corregida
    [new.csv]
2019-03-15 solo falta ajustar tiempo de integracion
2019-03-16 diseñando
    [Base Radar.stl, Base para Servo.stl, MEJORAS A MAZE ROBOT v11.stl]
2019-03-16 Listo para manufacturar y armar
    [ARDUINOMAINCONTROL.brd, ARDUINOMAINCONTROL.sch, CoverHCSR04.stl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]
2019-03-17 Codigo unido y listo para pruebas
2019-03-18 control de ejecucion por probar
2019-03-20 Circuit Project and Gcode to mill
    [ARDUINOMAINCONTROL.brd, ARDUINOMAINCONTROL.sch, syscharge.brd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]
2019-03-20 Sobenis Modificacion
    regreso de sonicos, cogida de motores y l298n
2019-03-21 cambios a pcb
    [ARDUINOMAINCONTROL.brd, ARDUINOMAINCONTROL.sch, syscharge.brd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]
2019-03-21 nuevo diseño para probar
    el codigo g esta para tip diameter 0.2mm trazas a 0.11mm(30 grados), grosor de placa 1.55, drills a 0.8mm
    [ARDUINOMAINCONTROL.brd, ARDUINOMAINCONTROL.sch]
2019-03-24 correciones antes de pruebas
2019-03-26 reduccion de codigos
2019-03-28 Piezas Sobenis
    Regreso de Piezas Sibenis
2019-03-31 LISTO PARA PROBAR
    INSTALAR LIBRERIA DE MPU 9250 Y HACER ECUACION PARA SERVO. AH PROBAR SE HA DICHO
2019-04-12 prueba, arduino carga con logica
2019-04-21 intento de regresion linear
    [reg0-45.xlsx]
2019-04-23 Simulaciones de codigo
    Mejoras requeridas en la adquisicion de data, problemas con valores 80 que significan no objeto. posible solucion disminuir baudrate.
    [reg0-180.xlsx, reg0-45.csv, reg0-45.xlsx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]
2019-04-24 prueba con dos barridos
    resultados iguales, decepcion emocional
    [reg0-180.xlsx]
2019-04-25 reducciond e velocidad de baudios
2019-04-25 mas pruebas
    [reg0-180.xlsx, reg0-45.csv, reg135-180.csv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]
2019-04-26 Listo para recoleccion de data en movimiento
2019-04-28 Cambio en logica de radar
    Se espera mejora en la toma de lecturas
2019-04-30 Diagrama de bloques de nueva pcb
2019-05-02 nuevo codigo de simulacion
    [reg0-180.xlsx]
2019-05-04 Update rpiard.py
    Funcion txdata actualizada con adaptacion de paquetes a 8 bytes, control de fin de visualizacion agregada, falta hacer servidor bluetooth y probar
2019-05-10 servidor de bluetooth corre en paralelo
2019-05-17 cambios requeridos para optimizar codigo
    se requieren realizar pruebas manuales y cargar bateria.
2019-05-18 Resultados de pruebas
    [PROYECTO DSP DATA DE 4 CASOS.xlsx, reg0-180.csv]
2019-05-18 Reduccion de caida de voltaje en L298N
    el led bajaba su intencidad debido a que el servo al llegar al extremo hacia mucho esfuerzo.
2019-05-29 Actualizacion de piezas ROBOCUP MAZE
2019-06-17 new parts
    [CONTROL.dxf, SISTEMA DE BATERIAS.dxf]
2019-06-19 ta ta tan
    [PROYECTO DSP DATA DE 4 CASOS (version 1).xlsx, reg0-180.csv]
2019-08-06 Create implementacion de encoder
2019-08-07 Log desconocido
    [Decision.csv, MinimoCuadrado.csv, radarData.csv]
2019-08-07 codigos implementados
    CODIGO PARA ENCODER
    CODIGO PARA CONTROL DE MOTORES DESDE LA RASPBERRY
    ESPERANDO PARA REVISION.

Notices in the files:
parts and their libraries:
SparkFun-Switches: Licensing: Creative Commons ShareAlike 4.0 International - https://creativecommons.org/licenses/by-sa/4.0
